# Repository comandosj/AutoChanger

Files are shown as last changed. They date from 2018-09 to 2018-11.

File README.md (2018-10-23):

AutoChanger - A Knitting Machine Auto Colour Changer to replace a Brother KRC-900
=============

This project was designed to provide a lower cost replacement for the commercial auto colour changer available from Brother for their 1980's electronic knitting machines.

You can read about the progress of this design at the following links:

[Building a better colour changer - Part 1 - Designing Hardware](http://heartofpluto.co/2017/04/25/building-a-better-colour-changer-part-1-designing-hardware/)

[Building a better colour changer - Part 2 - Firing the lasers](http://heartofpluto.co/2017/05/08/building-a-better-colour-changer-part-2-firing-the-lasers/)

[Building a Better Colour Changer – Part 3 – Revising the design](http://heartofpluto.co/2017/10/21/building-a-better-colour-changer-part-3-revising-the-design/)

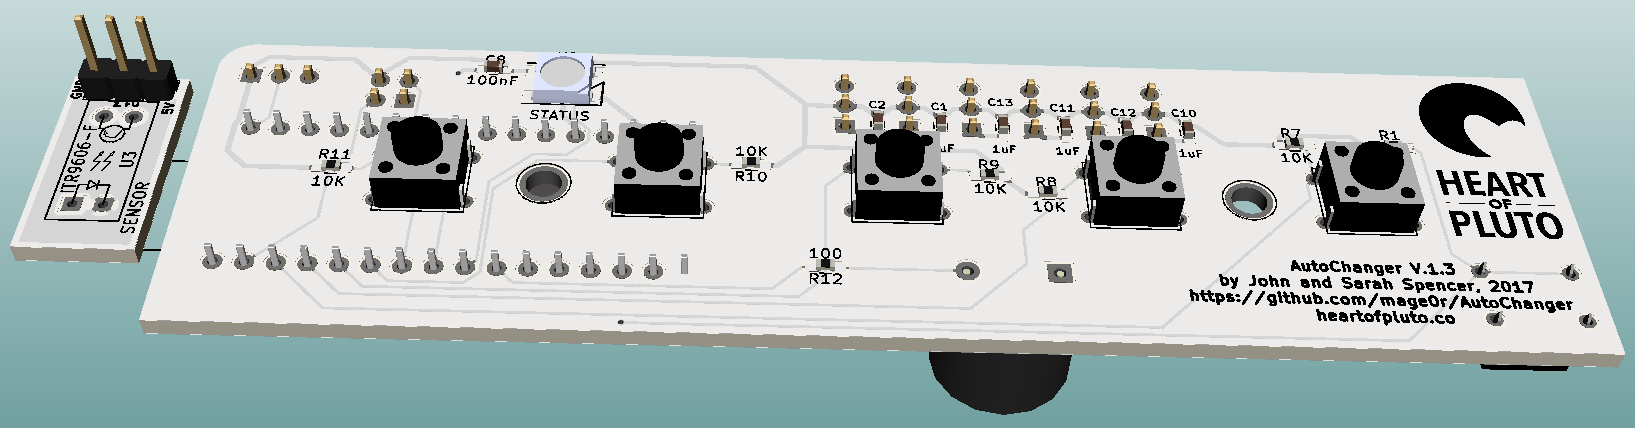
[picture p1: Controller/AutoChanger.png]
Circuit Board Render Circuit

The Arduino Nano based controller.

[Schematic Design](Controller/AutoChanger.pdf?raw=true "Schematic")

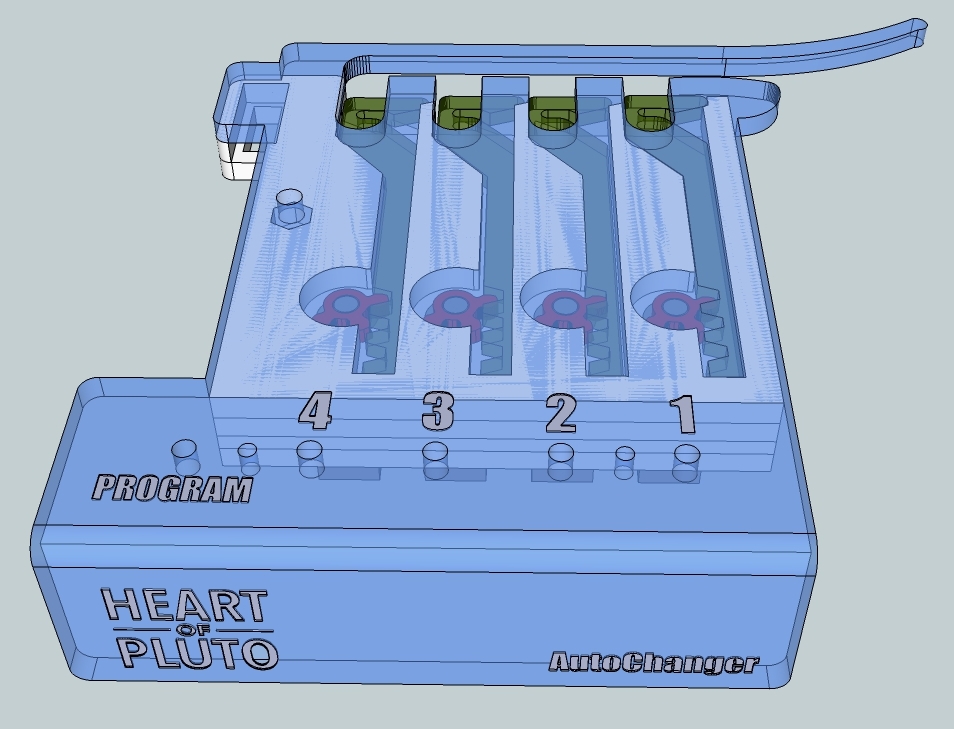
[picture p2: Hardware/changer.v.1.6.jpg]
Prototype Render Render


FEATURES
--------

* Arduino Uno compatible.
* Automatically change between 4 different colours.
* Audio guides.
* Programable colour order.

CREDITS
------------

This project was designed in 2017 by John and Sarah Spencer
 - [John Spencer](https://github.com/mage0r)
 - [Sarah Spencer](https://github.com/chixor)

Check us out at [Heart Of Pluto](http://heartofpluto.co)

Made at hackmelbourne.org!

SPECIAL THANKS
------------

To the HackMelbourne (CCHS, http://hackmelbourne.org) community of Melbourne, Australia.

To all other open-source developers whose countless hours supported every other aspect of this design.

DISTRIBUTION
------------
The specific terms of distribution of this project are governed by the
license referenced below. Please contact the copyright owner if you wish to modify the board for distribution. Please utilize this design for personal or research projects. Please acknowledge all contributors.

LICENSE
-------
Licensed under the TAPR Open Hardware License (www.tapr.org/OHL).
The "license" sub-folder also contains a copy of this license in plain text format.

Copyright John Spencer, Sarah Spencer, 2017

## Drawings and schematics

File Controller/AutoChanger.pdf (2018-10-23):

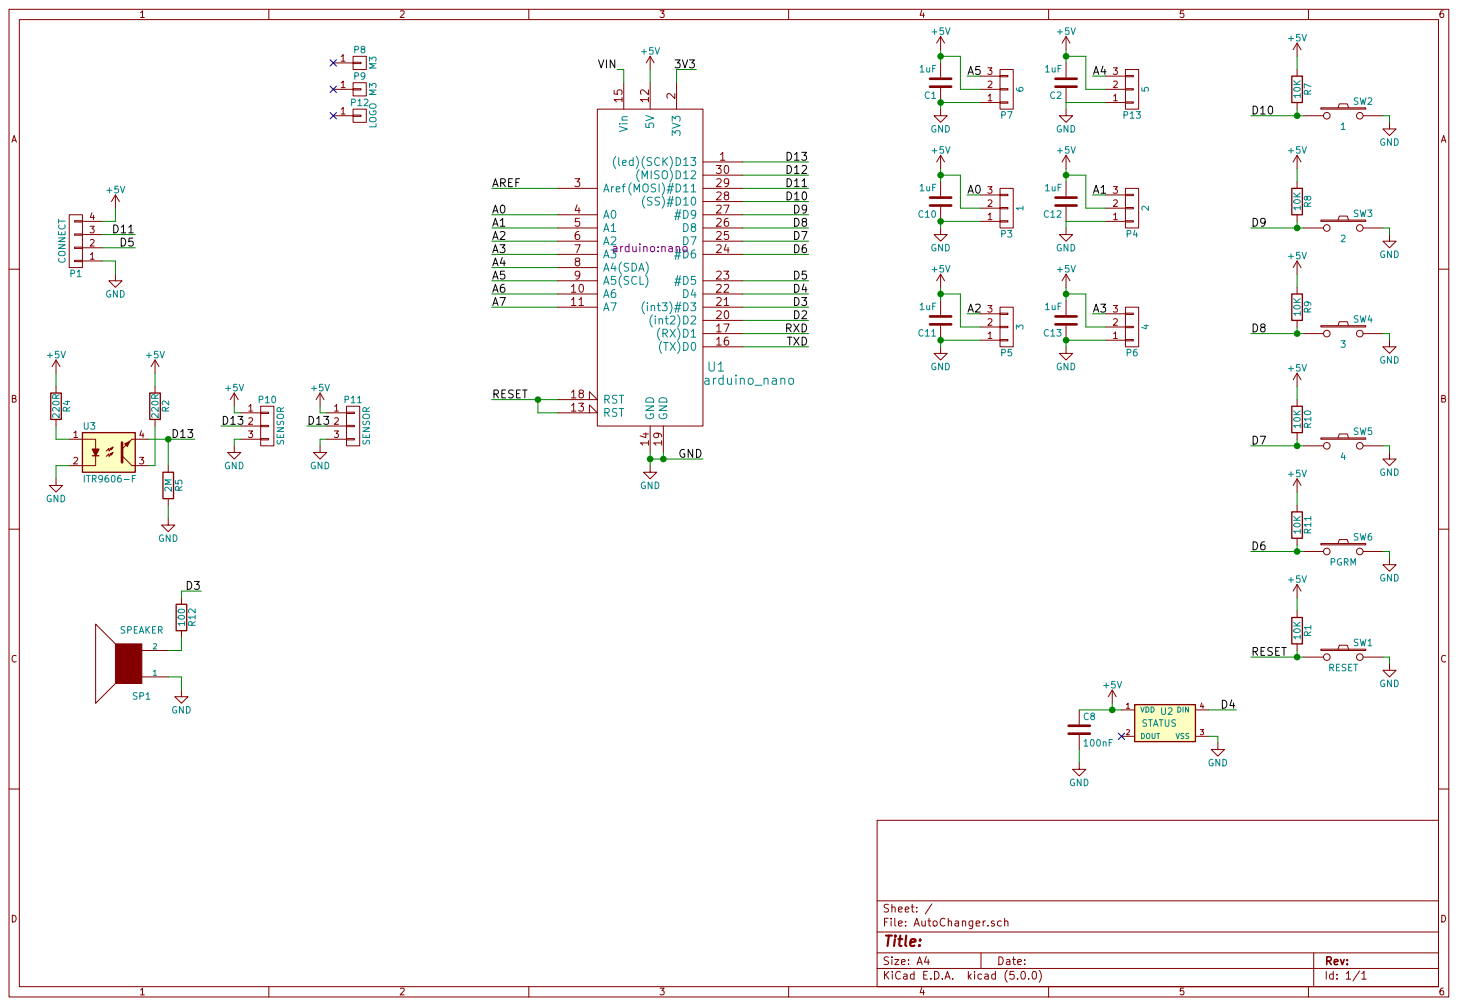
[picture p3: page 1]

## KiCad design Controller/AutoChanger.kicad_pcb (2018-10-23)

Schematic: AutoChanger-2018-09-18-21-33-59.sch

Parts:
C1, C2, C10, C11, C12, C13: 1uF; C_0603_HandSoldering
C8: 100nF; C_0603_HandSoldering
P1: CONNECT; Pin_Header_Straight_2x02_Pitch2.54mm
P3: 1; Pin_Header_Straight_1x03_Pitch2.54mm
P4: 2; Pin_Header_Straight_1x03_Pitch2.54mm
P5: 3; Pin_Header_Straight_1x03_Pitch2.54mm
P6: 4; Pin_Header_Straight_1x03_Pitch2.54mm
P7: 6; Pin_Header_Straight_1x03_Pitch2.54mm
P8, P9: M3; 1pin
P10, P11: SENSOR; Pin_Header_Straight_1x03_Pitch2.54mm
P12: LOGO; logo
P13: 5; Pin_Header_Straight_1x03_Pitch2.54mm
R1, R5, R7, R8, R9, R10, R11: 10K; R_0603_HandSoldering
R4: 220R; R_0603_HandSoldering
R12: 100; R_0603_HandSoldering
SP1: SPEAKER; Buzzer_12x9.5RM7.6
SW1: RESET; SW_PUSH_SMALL
SW2: 1; SW_PUSH_SMALL
SW3: 2; SW_PUSH_SMALL
SW4: 3; SW_PUSH_SMALL
SW5: 4; SW_PUSH_SMALL
SW6: PGRM; SW_PUSH_SMALL
U1: arduino_nano; nano
U2: STATUS; LED_WS2812B-PLCC4
U3: ITR9606-F; ITR9606

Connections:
+5V: C1.2, C2.2, C8.1, C10.2, C11.2, C12.2, C13.2, P1.4, P3.2, P4.2, P5.2, P6.2, P7.2, P10.1, P11.1, P13.2, R1.1, R4.1, R7.1, R8.1, R9.1, R10.1, R11.1, U1.12, U2.1; also elsewhere on the board
/3V3: U1.2
/A0: P3.3, U1.4
/A1: P4.3, U1.5
/A2: P5.3, U1.6
/A3: P6.3, U1.7
/A4: P13.3, U1.8
/A5: P7.3, U1.9
/A6: U1.10
/A7: U1.11
/AREF: U1.3
/D2: U1.20
/D3: R12.1, U1.21
/D4: U1.22, U2.4
/D5: P1.2, U1.23
/D6: R11.2, SW6.1, U1.24
/D7: R10.2, SW5.1, U1.25
/D8: R9.2, SW4.1, U1.26
/D9: R8.2, SW3.1, U1.27
/D10: R7.2, SW2.1, U1.28
/D11: P1.3, U1.29
/D12: U1.30
/D13: P10.2, P11.2, R5.1, U1.1, U3.4
/RESET: R1.2, SW1.1, U1.13, U1.18
/RXD: U1.17
/TXD: U1.16
/VIN: U1.15
GND: C1.1, C2.1, C8.2, C10.1, C11.1, C12.1, C13.1, P1.1, P3.1, P4.1, P5.1, P6.1, P7.1, P10.3, P11.3, P13.1, R5.2, SP1.1, SW1.2, SW2.2, SW3.2, SW4.2, SW5.2, SW6.2, U1.14, U1.19, U2.3, U3.2
unnamed 30: U3.3; also elsewhere on the board
unnamed: R4.2, U3.1
unnamed: R12.2, SP1.2

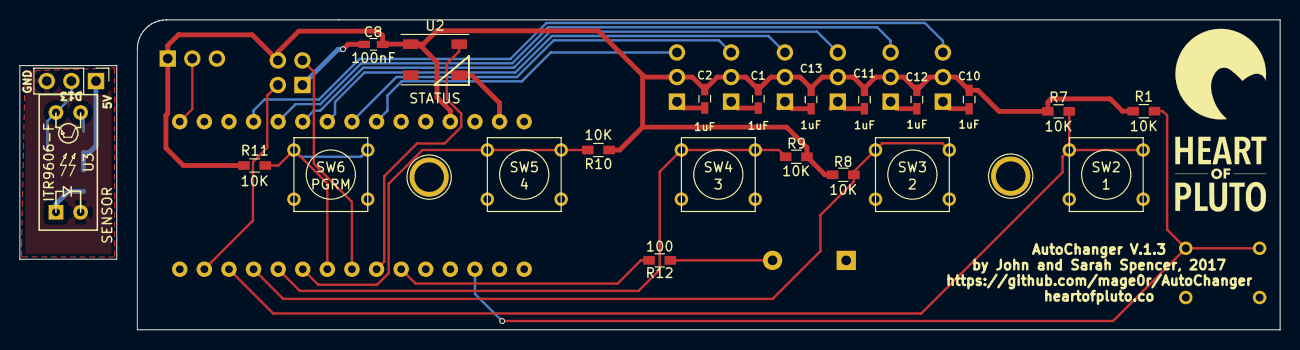
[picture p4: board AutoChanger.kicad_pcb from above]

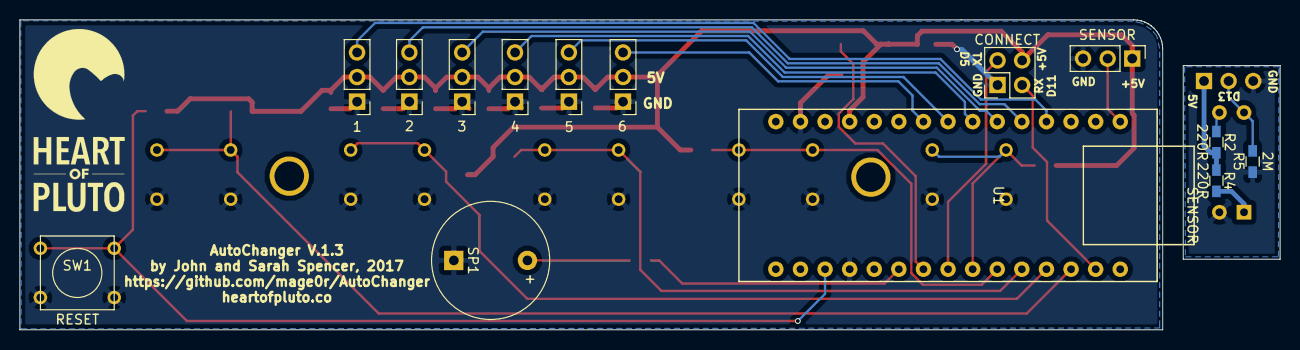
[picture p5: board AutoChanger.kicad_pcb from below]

Board: 2 copper layers, 118.0 x 32.0 mm, 40 parts (15 on the bottom side), 22 nets.

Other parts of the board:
P12#2: LOGO; logo
R2: 220R; R_0603_HandSoldering

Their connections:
+5V: R2.1; also elsewhere on the board
unnamed 30: R2.2; also elsewhere on the board

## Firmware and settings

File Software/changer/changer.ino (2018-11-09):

/*************************************************** 
 *  
 *  
 *  Autochanger - https://github.com/mage0r/AutoChanger
 *  
 *  This code is designed to run on an Arduino Nano 3.0 plugged in to the custom board in the repo.
 *  
 *  The Nano is flashed with a custom bootloader to enable EEPROM saving
 *  
 *  Oh god, please don't keep reading this code.  It is awful.
 *  
 *
 ****************************************************/

#include <Wire.h>
#include <Servo.h>
#include <Adafruit_NeoPixel.h>
#include <Bounce2.h>
#include <EEPROM.h>

#define DEBUG 1 // Do we want debug output on serial.
#define BUZZER 1 // Is the buzzer on or off.

// Set our version number.  Don't forget to update when featureset changes
#define VERSION "AutoChanger V.2.0"

// our Indicator light.
Adafruit_NeoPixel pixels = Adafruit_NeoPixel(1, 4, NEO_GRB + NEO_KHZ800);

// My Neopixels need a high and a low value.
byte color[2][3]; 

// The colour changer only uses 4 servos.
// content for this array is loaded from eeprom
byte servos[4][3];

Servo myservo[4];
unsigned long servoTimeout;

// our servo # counter
uint8_t servonum = 1;
uint8_t maxServo = 4;

// We track how many movements the servo has made.
// because, why not?! :)
unsigned int servoCount[4];
unsigned long EEPromTimeStamp;
unsigned int EEPromUpdateTime = 60000;


const int armPin = 13;
unsigned int buttonState;             // the current reading from the input pin
unsigned int lastButtonState = HIGH;   // the previous reading from the input pin
unsigned long lastDebounceTime = 0;  // the last time the output pin was toggled
unsigned long debounceDelay = 15;    // the debounce time; increase if the output flickers
byte armCounter = 0;  // We ignore every second pass.

// input buttons
// These are hardcoded
const int buttonPins[4] = {10,9,8,7};
const int pgrmPin = 6;

// Debouncing
Bounce debouncer[4] = Bounce();
byte previousButton;
Bounce pgrmDebouncer = Bounce();
unsigned long buttonPressTimeStamp;
boolean triggerPgrm = false;
boolean pgrmMode = false;
unsigned long pgrmTimeStamp = 0;
unsigned long pgrmLEDTime = 0;
byte temp_pattern[21] = {0,0,0,0,0,0,0,0,0,0,0,0,0,0,0,0,0,0,0,0,0}; // temporary pattern.

// Buzzer
const int buzzerPin = 3;

// Array of ints to store our pattern.
byte currentPattern = 0;
byte pattern[4][21];

// EEPROM Addresses
const int EEPROMServoCount = 10;
const int EEPROMServo = 50;
const int EEPROMPattern = 100;

void setup() {
  Serial.begin(115200);

  // First, build information
  Serial.println(F(VERSION));
  Serial.print(F("Build Date: "));
  Serial.println(F(__DATE__ " " __TIME__));
  Serial.print(F("Free Ram: "));
  Serial.println(freeRam());

  // get our previous settings.
  readEEPROM();

  pinMode(armPin, INPUT);

  for (int x = 0; x < 4; x++) {
    pinMode(buttonPins[x], INPUT);
    debouncer[x].attach(buttonPins[x]);
    debouncer[x].interval(5);
  }

  pinMode(pgrmPin, INPUT);
  pgrmDebouncer.attach(pgrmPin);
  pgrmDebouncer.interval(5);

  pinMode(buzzerPin, OUTPUT);

  // reset all the servo positions.
  for (int x = 0; x < maxServo; x++) {
    if(pattern[currentPattern][0] && pattern[currentPattern][1] == x)
      moveServo(x,2);
    else
      moveServo(x,1);
  }
  
  pixels.begin();
  //pixels.setPixelColor(0, pixels.Color(20,0,0));
  byte temp[3] = {20,0,0};
  setPixels(temp);
  pixels.show();

  // if the program pin is high, trigger a simulator mode.
  if(!digitalRead(pgrmPin)) {
    TestRun();
  } else if(!digitalRead(buttonPins[0])) {
    RestoreDefault(0);
  } else if(!digitalRead(buttonPins[1])) {
    RestoreDefault(1);
  } else if(!digitalRead(buttonPins[2])) {
    RestoreDefault(2);
  } else if(!digitalRead(buttonPins[3])) {
    RestoreDefault(3);
  }
  
}

void readEEPROM() {
  byte offset = 0;
  //Read our values from EEPROM

  // Read what the saved patterns.
  EEPROM.get(EEPROMPattern, pattern);
  if(DEBUG) {
    Serial.println(F("Patterns: "));
    for(int x = 0; x < 4; x++) {
      Serial.print(F("  "));
      for(int y = 0; y < 21; y++) {
        Serial.print(pattern[x][y]);
        Serial.print(F(":"));
      }
      Serial.println();
    }
  }

  // Read the Servo config.
  EEPROM.get(EEPROMServo, servos);
  if(DEBUG) {
    Serial.println(F("Servo Config: "));
    for(int x = 0; x < 4; x++) {
      Serial.print(F("  "));
      for(int y = 0; y < 3; y++) {
        Serial.print(servos[x][y]);
        Serial.print(F(":"));
      }
      Serial.println();
    }
  }
  

  // Read our current servo iterations.
  EEPROM.get(EEPROMServoCount,servoCount);

  // Show us how many actions each servo has made.
  // This happens even if not in debug mode
  Serial.println(F("Servo movement counts: "));
  for(int i = 0; i < 4; i++) {
    Serial.print(F("  Servo "));
    Serial.print(i);
    Serial.print(F(": "));
    Serial.println(servoCount[i]);
  }
}

void writeEEPROM() {
  // Every 60 seconds we update the eeprom.
  // This is safe and should only write if the value has changed.
  if ( millis() > EEPromTimeStamp+EEPromUpdateTime) {
    Serial.println(F("Updating EEPROM."));

    // update the patterns

    // no need to update the servo config, that can't be set in this sketch.

    // update the servo counts.
    EEPROM.put(EEPROMServoCount,servoCount);
    
    EEPromTimeStamp = millis();
  }
}

// we don't really need to hold the servos
// this function turns the servo on, moves it, then switches it off.
// x is the servo number.
// y is the position to move to in the "servos" array
void moveServo(int x, int y) {
  
  myservo[x].attach(servos[x][0]);

  if(myservo[x].read() != servos[x][y]) {
  // only update servoCount if the read position is different to where we're trying to get to.
    servoCount[x]++;
    
    myservo[x].write(servos[x][y]);
    if(DEBUG) {
      Serial.print(F("Moving Servo: "));
      Serial.print(x);
      if(y == 1)
        Serial.println(F(" down."));
      else
        Serial.println(F(" up."));
    }
  }
  
  servoTimeout = millis();
}

// after a given time, detach all servos.
void detachServo() {
  if(servoTimeout + 400 < millis()) {
    for (int x = 0; x < maxServo; x++) {
      myservo[x].detach();
    }
  }
}

void switchRods() {

  moveServo(pattern[currentPattern][servonum],1);

  servonum ++;
  
  if (servonum > pattern[currentPattern][0]) {
    if(DEBUG)
      Serial.println(F("Reset to start"));
    servonum = 1;
  }

  moveServo(pattern[currentPattern][servonum],2);

}

// kind of the wrong name for this function
// It handles when we EXIT program mode
void programMode() {
  // write our temp pattern to the array and reset the values to 0.
  // only do this if we actually have a pattern, i.e. more than 1 entry.
  if(temp_pattern[0] > 1) {
    byte temp_number = temp_pattern[0];
    for(int x = 0; x <= temp_number; x++) {
      // debug info
      if(DEBUG) {
        Serial.print(temp_pattern[x]);
        Serial.print(",");
      }
      
      // copy
      pattern[currentPattern][x] = temp_pattern[x];

      // reset
      temp_pattern[x] = 0;
    }
    if(DEBUG)
      Serial.println();

    // Update the eeprom.
    if(DEBUG)
      Serial.println("Writing new Pattern to memory.");
    EEPROM.put(EEPROMPattern,pattern);
  } else {
    Serial.println("No pattern detected.  Not updating.");
  }

  // reset our device to position 1.
  for (int x = 0; x < 4; x++) {
      moveServo(x,1);
  }
  servonum = 1;
  moveServo(pattern[currentPattern][servonum], 2);

}

void loop() {

  // Update our buttons.
  for (int x = 0; x < 4; x++) {
    debouncer[x].update();
  }
  pgrmDebouncer.update();

  // Check if we need to update the arm
  // We only need to do this if our pattern is non-zero
  // If the pattern is 0, it's a manual pattern
  if(pattern[currentPattern][0])
    checkArm();

  // run our button combo section
  checkButtons();

  
  if(pgrmMode){
    if(pgrmLEDTime < millis() - 200) { // if we're in program mode, flash our LED's
      if(pixels.getPixelColor(0) ==  0x000000)
        pixels.setPixelColor(0, pixels.Color(color[0][0],color[0][1],color[0][2]));
      else
         pixels.setPixelColor(0, pixels.Color(0,0,0));
      pgrmLEDTime = millis();
    }
  } else if(armCounter) // otherwise, set the colour dependent on the mode.
    pixels.setPixelColor(0, pixels.Color(color[1][0],color[1][1],color[1][2]));
  else
    pixels.setPixelColor(0, pixels.Color(color[0][0],color[0][1],color[0][2]));

  detachServo();

  pixels.show();

  writeEEPROM();
}

// look for our button combinations.
void checkButtons() {
  boolean pgrm = (!pgrmDebouncer.read());
  boolean one = (debouncer[0].fell());
  boolean two = (debouncer[1].fell());
  boolean three = (debouncer[2].fell());
  boolean four = (debouncer[3].fell());

  // There are several possible actions if number buttons are pressed
  // 1. If pgrm is also pressed, change pattern.
  // 2. If this is the active servo, cycle to the next in the sequence.
  // 3. If this is not the active servo, temporary swap
  // 4. If we have no pattern, swap servos.
  // 5. If pgrm is held down, go in to program mode.
  // We assume only one number button at a time.

  if(one) {
    byte temp[3] = {20,0,0};
    buttonActions(0, pgrm, temp);
  } else if (two) {
    byte temp[3] = {0,20,0};
    buttonActions(1, pgrm, temp);
  } else if (three) {
    byte temp[3] = {0,0,20};
    buttonActions(2, pgrm, temp);
  } else if (four) {
    byte temp[3] = {10,0,10};
    buttonActions(3, pgrm, temp);
  } else if (pgrm) {
    // first, reset the arm counter
    // It won't really matter if this happens before we head in to programming mode.
    if(armCounter != 0) {
      armCounter = 0;
      if(DEBUG)
        Serial.println(F("Arm Counter reset."));
    }

    // right, determine if the program button has been held down long enough to go in to programming mode.
    // start programming mode
    // Flash the LED's or something.
    if (pgrmTimeStamp == 0) {
      pgrmTimeStamp = millis();
    }
  } else {

    // ok. so the prgm button has been released.
    // lets decide what we want to do.
    // held down for more than 2 seconds?
    if (pgrmTimeStamp != 0 && pgrmTimeStamp + 2000 <= millis() ) {
      if(pgrmMode) {
        if(DEBUG)
          Serial.println("Exiting Programming mode.");
          
        pgrmMode = false;
        
        programMode();

      } else {
        if(DEBUG)
          Serial.println("Entering Programming mode.");

        // lets put all our arms down.
        for (int x = 0; x < 4; x++) {
            moveServo(x,1);
        }
        pgrmMode = true;
      }
    }
    
    pgrmTimeStamp = 0;
  }
}

void buttonActions(byte button, boolean pgrm, byte colours[3]) {
  
  // we repeat these actions a lot
  
   if(pgrmMode) { // We're in program mode.

      // put down the previous Servo.
      moveServo(servonum, 1);
      servonum = button;
      moveServo(servonum, 2);
      
      // iterate the temp pattern number.
      temp_pattern[0]++;
      // Add this button to the temp_pattern.
      temp_pattern[temp_pattern[0]] = button;

      if(temp_pattern[0] == 20) {
        pgrmMode = false;
        if(DEBUG)
          Serial.println("Limit Reached.  Exiting Program Mode.");
        programMode();
      }
      
    } else if(pgrm) {
      // ok, this only needs to happen if our current servo isn't already the one we want to switch to
      if(pattern[currentPattern][servonum] != pattern[button][1]) {
        moveServo(pattern[currentPattern][servonum],1); // put our current servo down.
      } else if (!pattern[currentPattern][0] && pattern[button][1] != servonum) {
        // special edge case, if our previous pattern was empty, put all the servos down.
        // oh, and we re-used servonum to act as our current servo, rather than a position in the
        // pattern array.
        for (int x = 0; x < 4; x++) {
            moveServo(x,1);
        }
      }
      
      currentPattern = button;
      servonum = 1; // first in the pattern.
      // only need to do stuff if the pattern is active
      if( pattern[currentPattern][0]) {
        moveServo(pattern[currentPattern][servonum],2);
      }
      
      setPixels(colours);
    } else if (!pattern[currentPattern][0]) {
      // No pattern
      // this is a special case.  flip one up or down.
      for (int x = 0; x < 4; x++) {
        if(x == button) {
          if(servonum == button) {
            moveServo(x,1); // move down.
            servonum = -1;
          } else {
            moveServo(x,2); // move up
            servonum = button;
          }
        } else {
          moveServo(x,1);
        }
      }
    } else if (pattern[currentPattern][servonum] == button) {
      // This is the active servo.
      switchRods();
    }
}

void setPixels(byte colours[3]) {
  byte tempColor1[] = {colours[0], colours[1], colours[2]};
  memcpy(color[0],tempColor1,3);
  byte tempColor2[] = {colours[0]*2, colours[1]*2, colours[2]*2};
  memcpy(color[1],tempColor2,3);
}


// Just pull this out in to it's own function to make this easier to read.
void checkArm() {
  int reading = digitalRead(armPin);

  // If the switch changed, due to noise or pressing:
  if (reading != lastButtonState) {
    // reset the debouncing timer
    lastDebounceTime = millis();
  }

  if ((millis() - lastDebounceTime) > debounceDelay) {
    // whatever the reading is at, it's been there for longer
    // than the debounce delay, so take it as the actual current state:

    // if the button state has changed:
    if (reading != buttonState) {
      buttonState = reading;

      if (buttonState == LOW) {
        if(armCounter == 0){
          switchRods();
          armCounter = 1;

          // Turn the buzzer on for 1 second
          if(BUZZER)
            tone(buzzerPin, "c", 1000);
        }
        else
          armCounter = 0;
      }
    }
  }

  // save the reading.  Next time through the loop,
  // it'll be the lastButtonState:
  lastButtonState = reading;
}

void TestRun() {
  // Trigger a testrun if the program button is held down during start.

  pixels.setPixelColor(0, pixels.Color(20,20,20));
  pixels.show();
  delay(100);

  Serial.println(F("Entering Test Mode."));
  Serial.println(F("Executing 100 cycles of the servos."));
  
  for (int y = 0; y < 100; y++) {
    for (int x = 0; x < maxServo; x++) {
      if(x == 0) {
        moveServo(maxServo-1,1);
        pixels.setPixelColor(0, pixels.Color(20,0,0));
      } else
        moveServo(x-1,1);

      if( x == 1)
        pixels.setPixelColor(0, pixels.Color(0,20,0));
      else if( x == 2)
        pixels.setPixelColor(0, pixels.Color(0,0,20));
      else if( x == 3)
        pixels.setPixelColor(0, pixels.Color(10,0,10));
        
      moveServo(x,2);

      
      pixels.show();
      delay(400);
      writeEEPROM(); // update the eeprom if needed.
    }
  }
}

void RestoreDefault(byte button) {
  // Restore the default patterns!

  static byte defaultPattern[4][21] = {
    {2,0,1,0,0,0,0,0,0,0,0,0,0,0,0,0,0,0,0,0,0},
    {3,0,1,2,0,0,0,0,0,0,0,0,0,0,0,0,0,0,0,0,0},
    {4,0,1,2,3,0,0,0,0,0,0,0,0,0,0,0,0,0,0,0,0},
    {0,0,0,0,0,0,0,0,0,0,0,0,0,0,0,0,0,0,0,0,0},
  };

  for(int i = 0; i < 21; i++) {
    pattern[button][i] = defaultPattern[button][i];
  }

  // Write them back to our ram
  EEPROM.put(EEPROMPattern,pattern);

  if(DEBUG) {
    Serial.print("Default Pattern restored for Pattern ");
    Serial.print(button);
    Serial.println(".");

    Serial.println(F("Patterns: "));
    for(int x = 0; x < 4; x++) {
      Serial.print(F("  "));
      for(int y = 0; y < 21; y++) {
        Serial.print(pattern[x][y]);
        Serial.print(F(":"));
      }
      Serial.println();
    }
  }
}

int freeRam(void)
{
  extern int __heap_start, *__brkval; 
  int v; 
  return (int) &v - (__brkval == 0 ? (int) &__heap_start : (int) __brkval); 
}

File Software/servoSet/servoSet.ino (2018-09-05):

/*************************************************** 

  This sketch is intended to set the precise positions of the servos
  for the Autochanger, and save this configuration in to the eeprom.

 ****************************************************/

#include <Wire.h>
#include <Servo.h>
#include <EEPROM.h>
#include <Bounce2.h>

// The colour changer only uses 4 servos.
byte servos[4][3] = {
  {A0,0,100},
  {A1,0,100},
  {A2,0,100},
  {A3,0,100},
};

unsigned int servoCount[4] = {0,0,0,0};

// don't forget, our servo's start at 0!
byte pattern[4][21] = {
  {2,0,1,0,0,0,0,0,0,0,0,0,0,0,0,0,0,0,0,0,0},
  {3,0,1,2,0,0,0,0,0,0,0,0,0,0,0,0,0,0,0,0,0},
  {4,0,1,2,3,0,0,0,0,0,0,0,0,0,0,0,0,0,0,0,0},
  {0,0,0,0,0,0,0,0,0,0,0,0,0,0,0,0,0,0,0,0,0},
};

const int buttonPins[4] = {10,9,8,7};
Bounce debouncer[4] = Bounce();
unsigned long buttonPressTimeStamp;
unsigned long lastDebounceTime = 0;  // the last time the output pin was toggled
unsigned long debounceDelay = 1;    // the debounce time; increase if the output flickers

Servo myservo[4];

// our servo # counter
uint8_t servonum = 0;

// EEPROM Addresses
const int EEPROMServoCount = 10;
const int EEPROMServo = 50;
const int EEPROMPattern = 100;

void setup() {
  Serial.begin(115200);

  for (int x = 0; x < 4; x++) {
      myservo[x].attach(servos[x][0]);
      myservo[x].write(servos[x][1]);
      Serial.print("Servo ");
      Serial.print(x);
      Serial.print(": Position ");
      Serial.println(servos[x][1]);
      delay(600);
      myservo[x].detach();
  }

  for (int x = 0; x < 4; x++) {
    pinMode(buttonPins[x], INPUT);
    debouncer[x].attach(buttonPins[x]);
    debouncer[x].interval(5);
  }

  writeEEPROM();

  // this resets the servo counts.
  // Don't use it.
  //EEPROM.put(EEPROMServoCount,servoCount);
  
}

void loop() {
  for (int x = 0; x < 4; x++) {
    debouncer[x].update();
  }

  checkButtons();
}

void writeEEPROM() {

  // Write the servos
  Serial.println("Servo configs");
  for(int i = 0; i< 4; i++) {
    for(int j = 0; j < 3; j++) {
      Serial.print(servos[i][j]);
      Serial.print(":");
    }
    Serial.println();
  }

  EEPROM.put(EEPROMServo,servos);

  //Write the Patterns
  Serial.println("Patterns");
  for(int i = 0; i< 4; i++) {
    for(int j = 0; j < 21; j++) {
      Serial.print(pattern[i][j]);
      Serial.print(":");
    }
    Serial.println();
  }
  EEPROM.put(EEPROMPattern,pattern);
  
}

void checkButtons() {
  
  for (int x = 0; x < 4; x++) {
      //Serial.println(debouncer[x].read());
      
      if(!debouncer[x].read()){
        myservo[x].write(servos[x][2]);
        myservo[x].attach(servos[x][0]);
        delay(600);
        myservo[x].detach();
      }
      else if (myservo[x].read() != servos[x][1]){
        myservo[x].write(servos[x][1]);
        myservo[x].attach(servos[x][0]);
        delay(600);
        myservo[x].detach();
      }
      
  }
}

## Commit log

2017-05-14 Initial Upload
    [AutoChanger.kicad_pcb, AutoChanger.sch]
2017-05-19 Added a buzzer and moved pins.
    [AutoChanger.kicad_pcb, _saved_AutoChanger.sch]
2017-05-27 Adding schematic pdfs and license
    [AutoChanger.kicad_pcb, AutoChanger.sch, _saved_AutoChanger.sch]
2017-05-27 Updated design.
    [AutoChanger.kicad_pcb]
2017-06-25 Updated board design.
    Heaps more caps. Thanks @projectgus
    [AutoChanger.kicad_pcb, AutoChanger.sch]
2017-06-25 Revised the size of gear shaft.
2017-08-25 Updated design
    [AutoChanger.kicad_pcb, AutoChanger.sch]
2017-09-11 Updated circuit board
    [AutoChanger.kicad_pcb, AutoChanger.sch]
2017-10-05 Updated version
    [AutoChanger.kicad_pcb, AutoChanger.sch]
2017-10-19 New Nano version
    [AutoChanger.kicad_pcb, AutoChanger.sch]
2017-10-19 Updated 3d settings.
    [AutoChanger.kicad_pcb]
2018-09-05 Updated designs across the board
    So, lots of small changes as I've tweaked the design.
    In order to improve manufacturing, I've changed to 3d printing the main body.
    [AutoChanger.kicad_pcb, AutoChanger.sch, changer.v.1.6.solid.m3d.pt2.stl]
2018-09-05 Lets ignore stl files
2018-10-23 Updated sub board
    [AutoChanger-2018-09-18-21-33-59.sch, AutoChanger.kicad_pcb]
2018-10-23 File cleanup
    [changer.v.1.6.solid.m3d.pt2.stl]
2018-11-09 Big code update. Feature Complete maybe?
    The firmware now allows full pattern reprogramming.
    As a special bonus, in manual mode arms can be toggled.
    As a special, special bonus, you can reset the program to the default by
    holding the number buttons while starting the unit!
    [changer.ino]
2018-11-09 Debounce delay way to high
    So, playing with deboucing and did a test to set it to stupid large
    number.
    Forgot to reset that....
    [changer.ino]
